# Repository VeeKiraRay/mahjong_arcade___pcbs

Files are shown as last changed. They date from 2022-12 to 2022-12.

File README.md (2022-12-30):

# Mahjong arcade DIY control panels
Kicad projects for a small mahjong control panel pcb that can be wired to be used with a real arcade game

Inspired by buffis JammaMahjongAdapter
https://github.com/buffis/JammaMahjongAdapter

Mahjong pinout that was followed when designing these
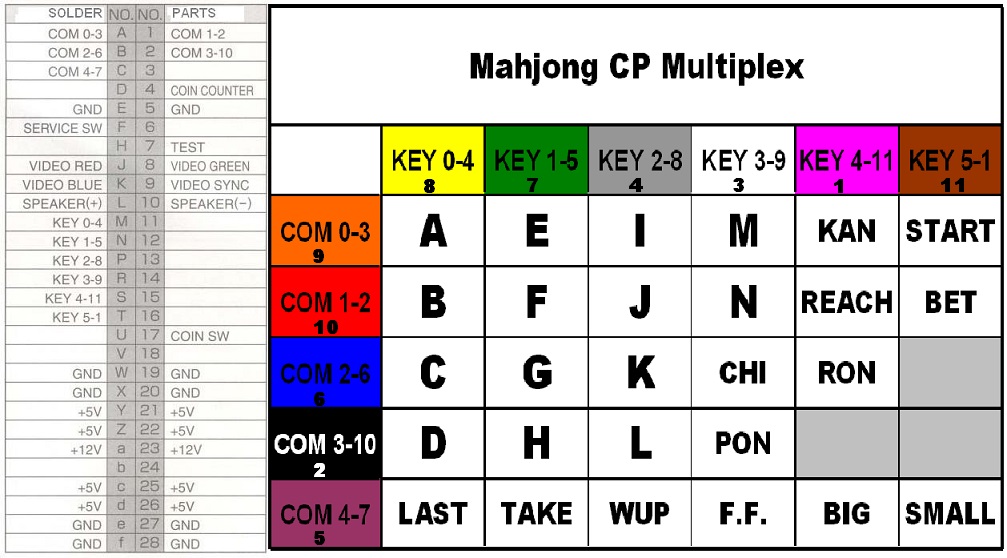
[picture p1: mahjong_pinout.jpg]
Mahjong pinout img


Comparison with different versions next to "Hot Gimmick 3" arcade pcb. Added a commercial version for Windows as a size comparison as well. 
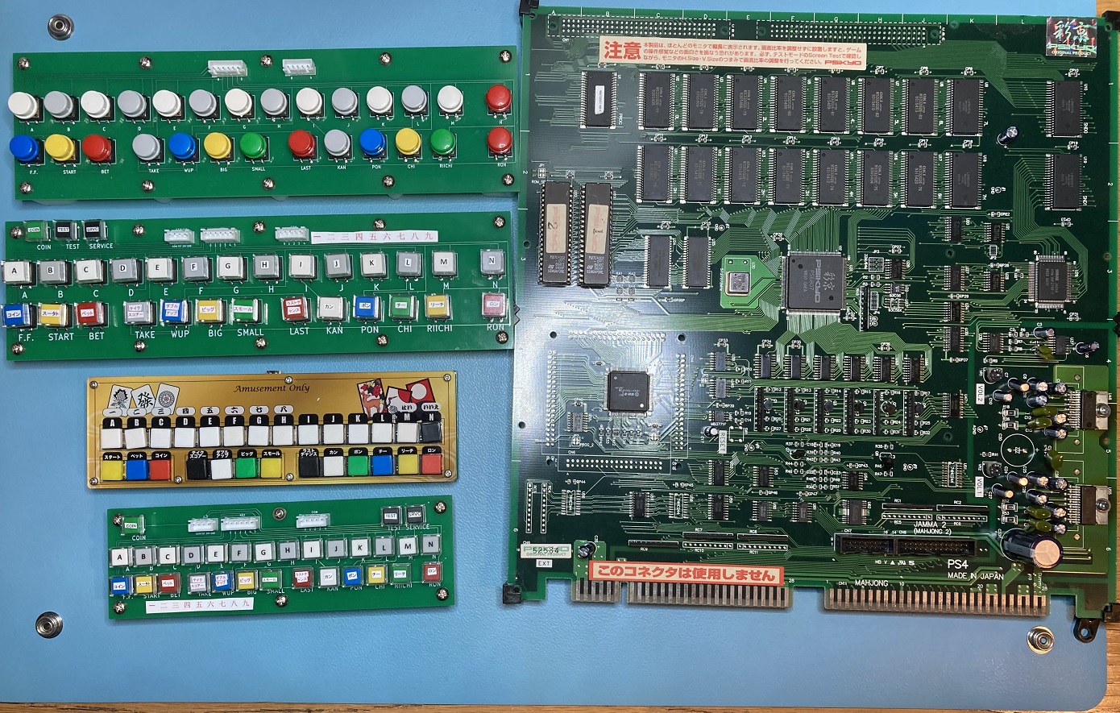
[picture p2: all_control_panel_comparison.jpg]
Comparison img


Ready to play with small control panel and mahjong to jamma adapter
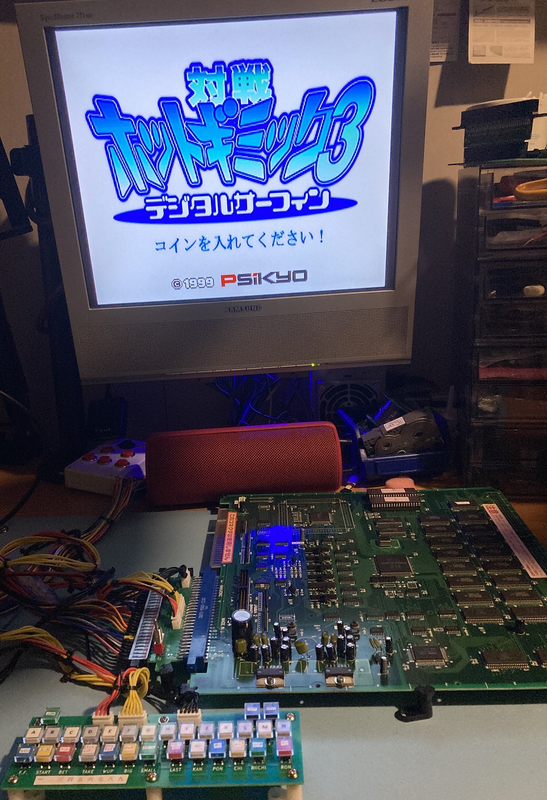
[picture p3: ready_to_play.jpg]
Ready_to_play img


## Mahjong control panel symbols
For printing stickers or otherwise marking control panels here are some of the common characters to use

Lower part of control panel
- coin (F.F.) / ko-i-n / コイン
- start / su-ta-a-to / スタート 
- bet / be-t-to / ベット
- take score / te-i-ku-su-ko / テイクスコアー
- double up (WUP) / da-bu-ru a-p-pu / ダブルアップ  
- big / bi-g-gu / ビッグ
- small / su-mo-ru / スモール
- last chance / ra-su-to ch-a-n-su / ラストチャンス
- kan / ka-n / カン
- pon / po-n / ポン
- chi / ch-i / チー
- riichi / ri-i-chi / リーチ
- ron / ro-n / ロン

Character suite to number conversion
- 1 / 一
- 2 / 二
- 3 / 三
- 4 / 四
- 5 / 五
- 6 / 六
- 7 / 七
- 8 / 八
- 9 / 九

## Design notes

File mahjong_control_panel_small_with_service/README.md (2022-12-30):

# Mahjong control panel small with service buttons

Smaller version of control panel with basic inputs and additional buttons for easy coin in, test for menus and service for alternative coin in and options.

- Connectors are with 2.5mm pitch, but 2.54mm should also work
- All buttons are 6mm. Any correct size button should work with or without the hats.
- Holes at the edge are M3 for attaching legs or to a case.

Bare pcb
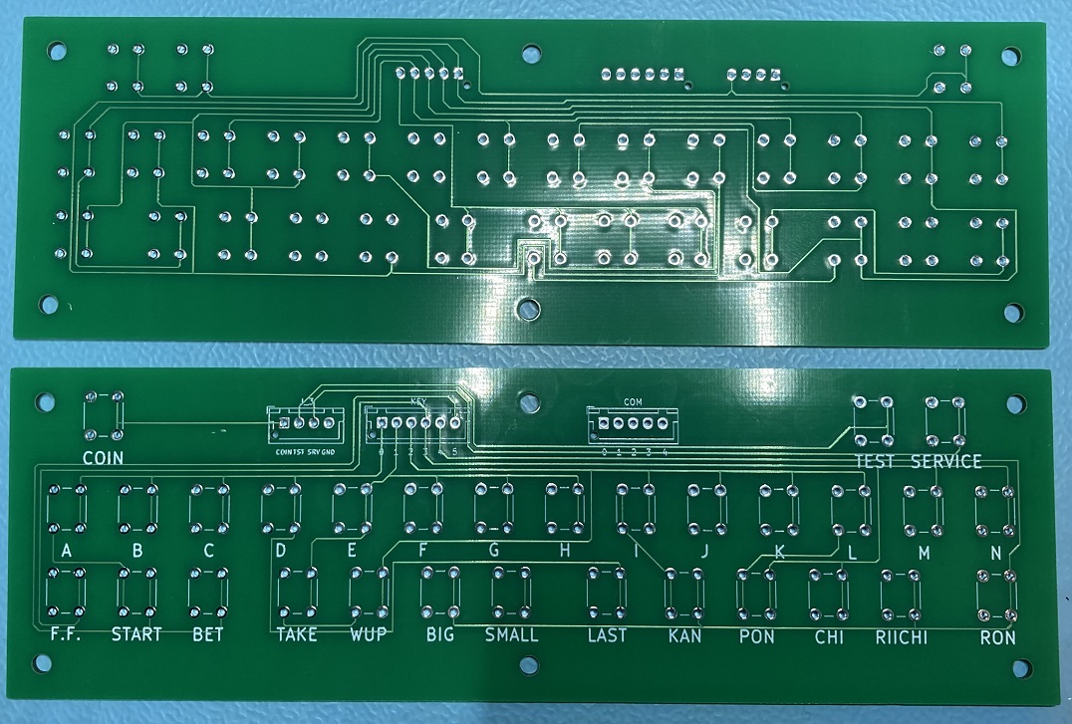
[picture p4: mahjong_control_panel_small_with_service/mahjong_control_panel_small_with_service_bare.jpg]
Bare pcb img


Control panel poulated
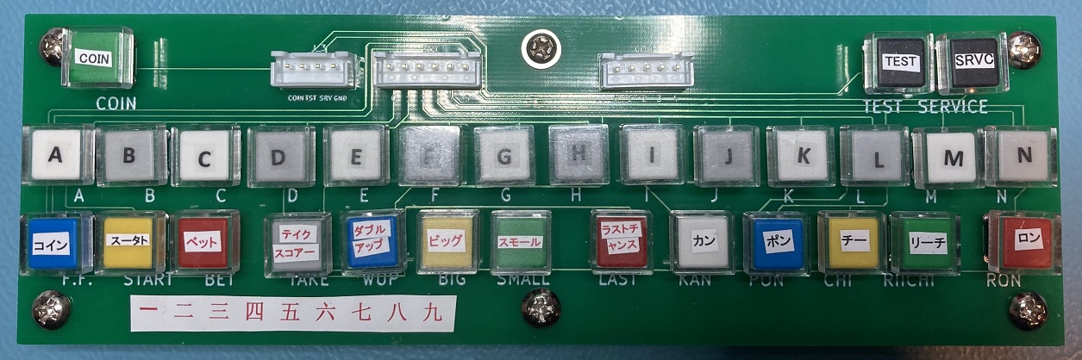
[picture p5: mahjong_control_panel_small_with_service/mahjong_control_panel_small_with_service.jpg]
Control panel populated img


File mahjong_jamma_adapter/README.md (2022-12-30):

# Mahjong to JAMMA adapter

Enables you to play Mahjong games in a JAMMA setup like arcade cabinet or supergun. 
This has 3.96mm pitch for the mahjong side pads which is same as with JAMMA. Note that some Mahjong games use 4mm pitch.
Be sure to check that the adapter lines with the game pcb pads correctly.

The main Mahjong controls can be extended with the 6- and 5-pin connectors. 
Additional 4-pin connector is also available for wiring coin, test and service buttons with GND.
Connector pins are with 2.5mm pitch, but 2.54mm should also work.

The -5V requirement and GND to "JAMMA Spk-" can be bridged if needed.

Audio section can be wired with a switch to change between connecting "JAMMA Spk-" to "Mahjong Spk-" or to GND.
Be sure what connections your game(s) require. For example Hot Gimmick needs the "JAMMA Spk-" to be connected to "Mahjong Spk-" or there won't be any sound.
Connecting this wrong can cause sound to be missing, distorted, low volume and possibly components overheating.

Mahjong pinout that was followed when designing this
Mahjong pinout img

Bare pcb
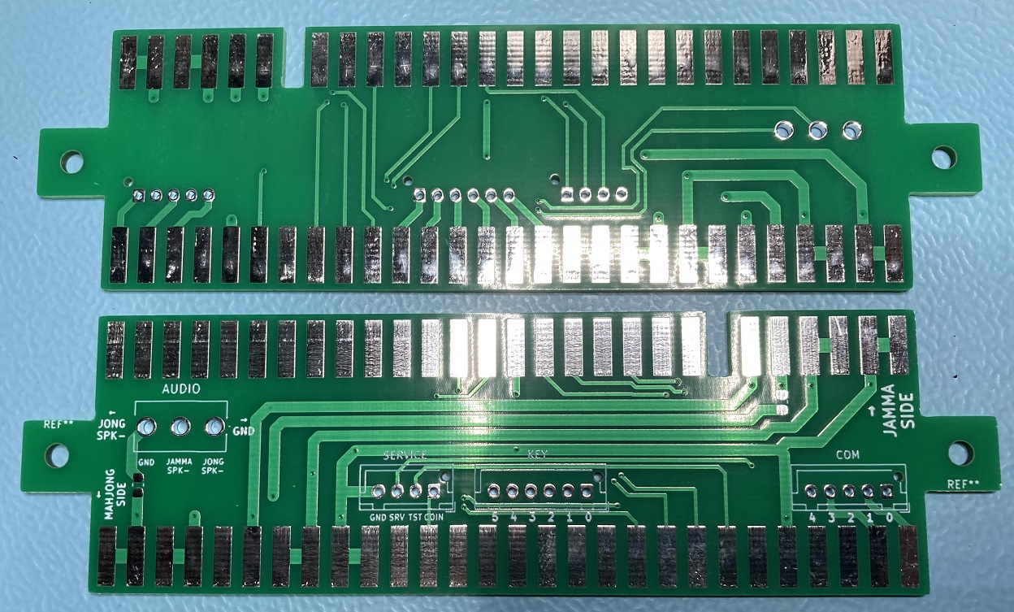
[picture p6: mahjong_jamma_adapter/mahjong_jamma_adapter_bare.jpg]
Bare pcb img


Control panel poulated
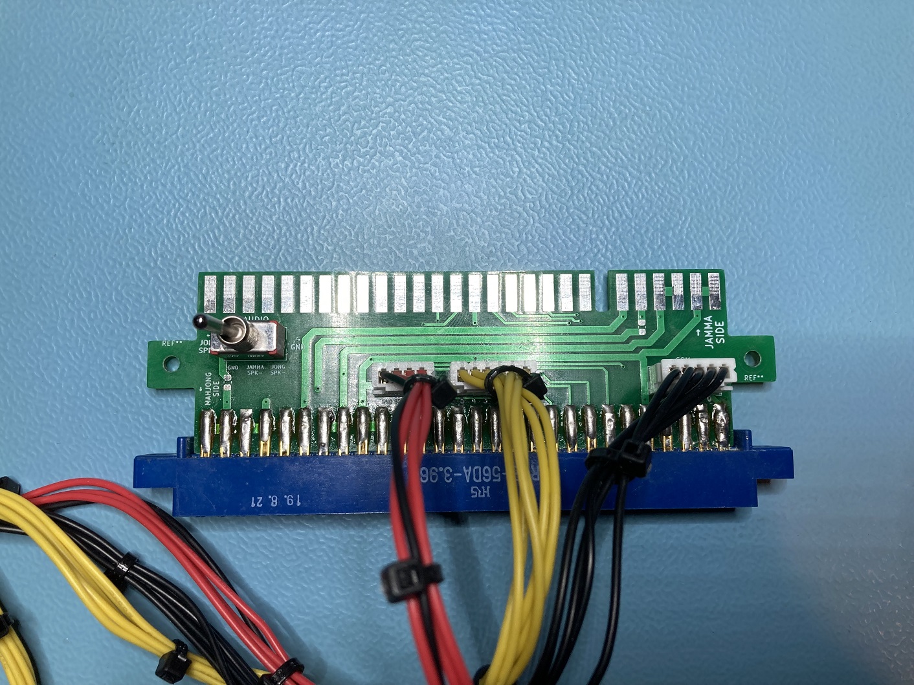
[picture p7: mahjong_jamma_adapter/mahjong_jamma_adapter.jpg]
Adapter populated img


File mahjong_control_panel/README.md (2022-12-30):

# Mahjong control panel

Control panel with just the basic inputs

- Connectors are with 2.5mm pitch, but 2.54mm should also work
- Main buttons are 12mm buttons. Any correct size button should work with or without the hats.
- Holes at the edge are M3 for attaching legs or to a case.

Bare pcb
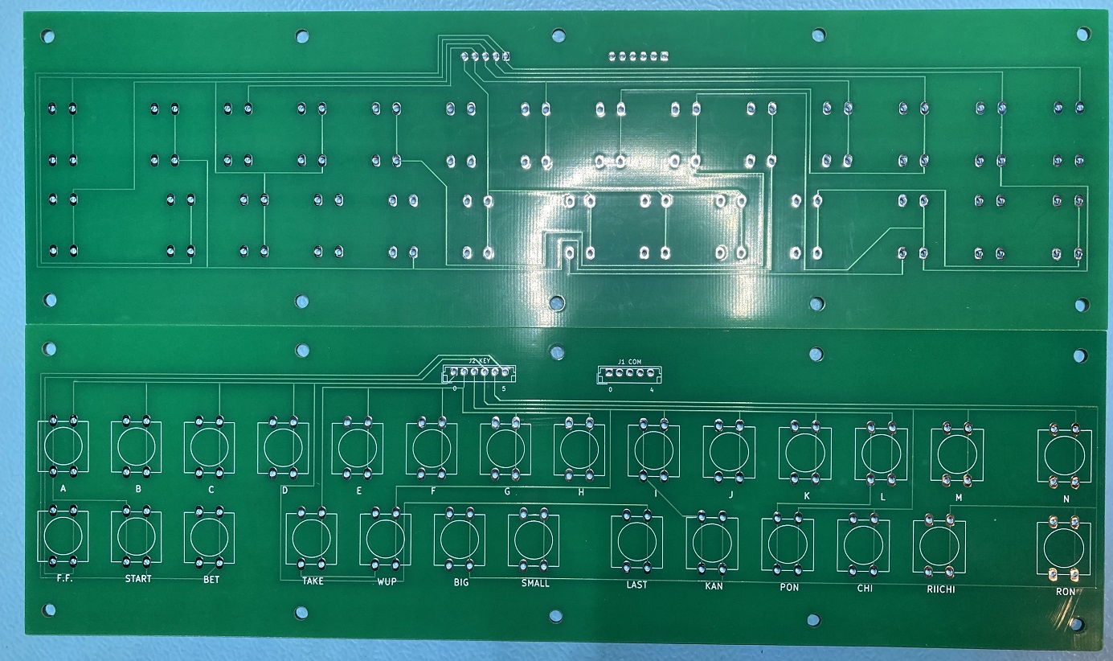
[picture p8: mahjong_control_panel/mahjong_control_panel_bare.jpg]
Bare pcb img


Control panel poulated
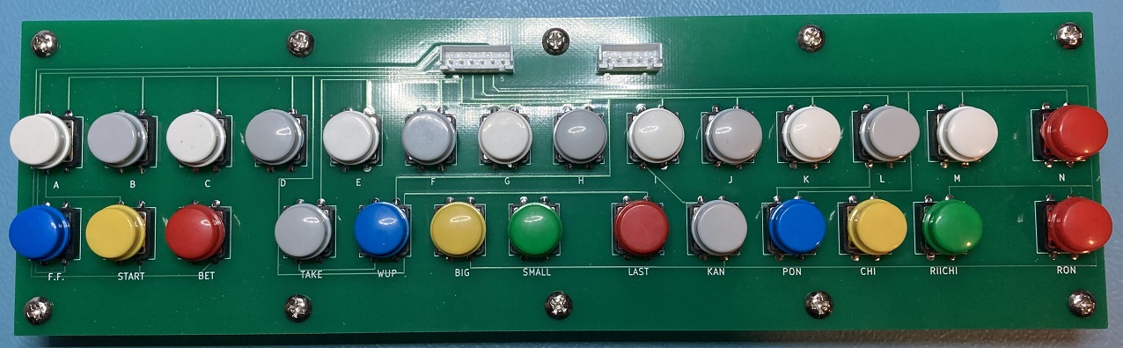
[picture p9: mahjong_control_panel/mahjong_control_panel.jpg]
Control panel populated img


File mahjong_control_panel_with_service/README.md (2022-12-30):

# Mahjong control panel with service buttons

Control panel with basic inputs and additional buttons for easy coin in, test for menus and service for alternative coin in and options.

- Connectors are with 2.5mm pitch, but 2.54mm should also work
- Main buttons are 12mm buttons and service buttons are 6mm. Any correct size button should work with or without the hats.
- Holes at the edge are M3 for attaching legs or to a case.

Bare pcb
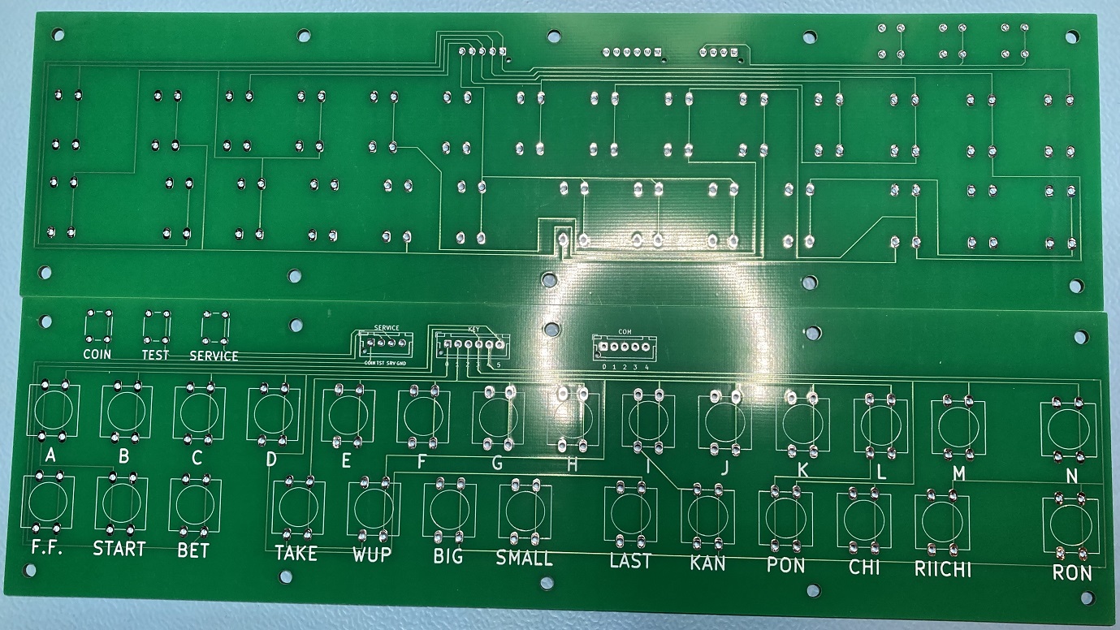
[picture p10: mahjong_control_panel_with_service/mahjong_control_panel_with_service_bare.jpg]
Bare pcb img


Control panel poulated
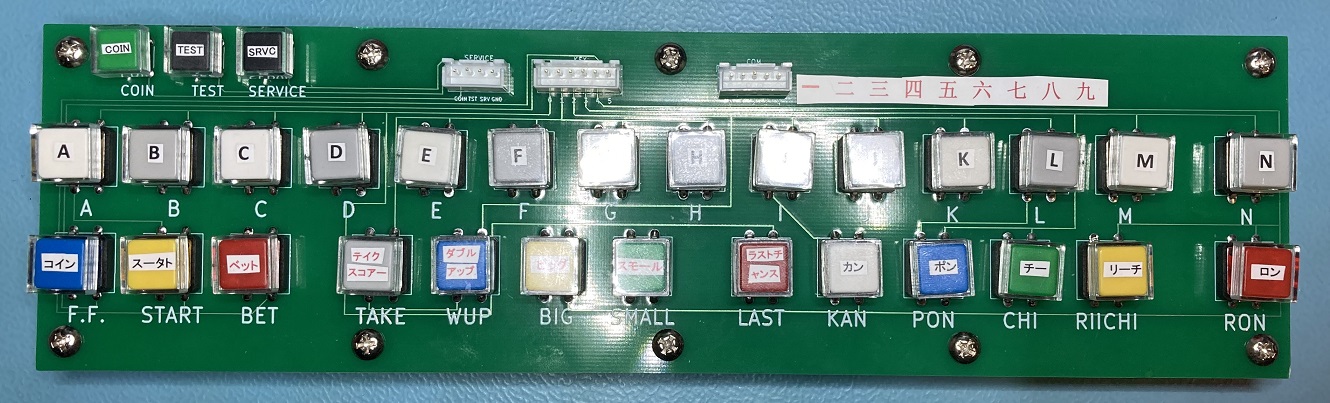
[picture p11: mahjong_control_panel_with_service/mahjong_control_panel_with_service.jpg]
Control panel populated img


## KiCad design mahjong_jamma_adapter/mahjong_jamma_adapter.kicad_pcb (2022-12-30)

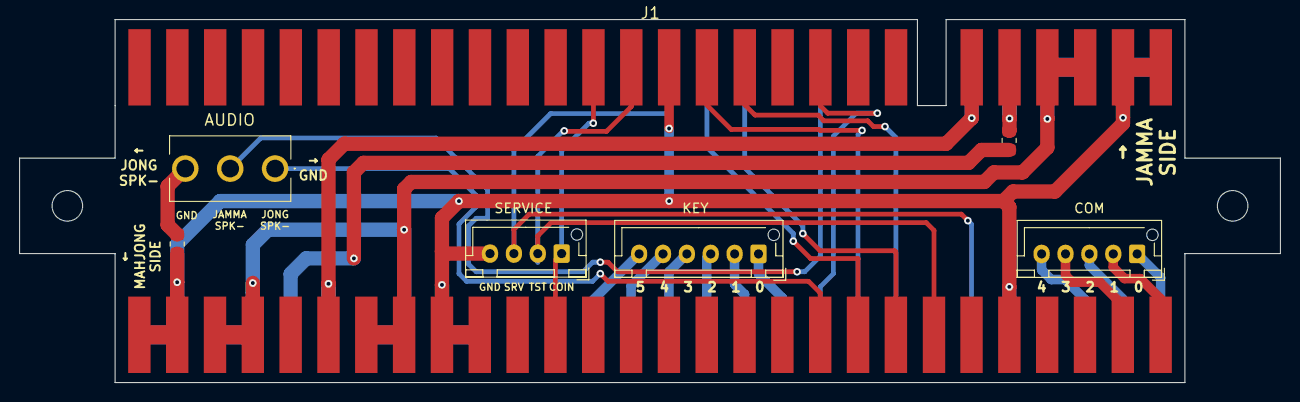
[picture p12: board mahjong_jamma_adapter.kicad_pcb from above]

Board: 2 copper layers, 132.0 x 38.0 mm, 8 parts (0 on the bottom side), 27 nets.

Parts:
AUDIO: Mahjong_Connector; MAHJONG-56
COM: Conn_01x05; JST_XH_B5B-XH-AM_1x05_P2.50mm_Vertical
J1: Jamma_Connector; JAMMA-56
JMP1, JMP2: SolderJumper_2_Open; R_0805_2012Metric_Pad1.20x1.40mm_HandSolder
KEY: Conn_01x06; JST_XH_B6B-XH-AM_1x06_P2.50mm_Vertical
SERVICE: Conn_01x04; JST_XH_B4B-XH-AM_1x04_P2.50mm_Vertical
SW1: SW_SPDT; A101SYCQ04

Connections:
5V: AUDIO.21, AUDIO.22, AUDIO.25, AUDIO.26, AUDIO.Y, AUDIO.Z, AUDIO.c, AUDIO.d, J1.3, J1.4, J1.C, J1.D
12V: AUDIO.23, AUDIO.a, J1.6, J1.F
-5V: J1.5, J1.E, JMP1.2 (B)
-5V_M: AUDIO.b, JMP1.1 (A)
BLUE: AUDIO.K, J1.13
COIN: AUDIO.17, J1.16, SERVICE.1
COM0-3: AUDIO.A, COM.1
COM1-2: AUDIO.1, COM.2
COM2-6: AUDIO.B, COM.3
COM3-10: AUDIO.2, COM.4
COM4-7: AUDIO.C, COM.5
GND: AUDIO.5, AUDIO.19, AUDIO.20, AUDIO.27, AUDIO.28, AUDIO.E, AUDIO.W, AUDIO.X, AUDIO.e, AUDIO.f, J1.1, J1.2, J1.14, J1.A, J1.B, JMP2.2 (B), SERVICE.4
GREEN: AUDIO.8, J1.N
JAMMA_SPK-: J1.L, SW1.2 (B)
JONG_SPK-: AUDIO.10, SW1.1 (A)
KEY0-4: AUDIO.M, KEY.1
KEY1-5: AUDIO.N, KEY.2
KEY2-8: AUDIO.P, KEY.3
KEY3-9: AUDIO.R, KEY.4
KEY4-11: AUDIO.S, KEY.5
KEY5-1: AUDIO.T, KEY.6
unnamed: JMP2.1 (A), SW1.3 (C)
RED: AUDIO.J, J1.12
SERVICE: AUDIO.F, J1.R, SERVICE.3
SPK+: AUDIO.L, J1.10
SYNC: AUDIO.9, J1.P
TEST: AUDIO.7, J1.15, SERVICE.2

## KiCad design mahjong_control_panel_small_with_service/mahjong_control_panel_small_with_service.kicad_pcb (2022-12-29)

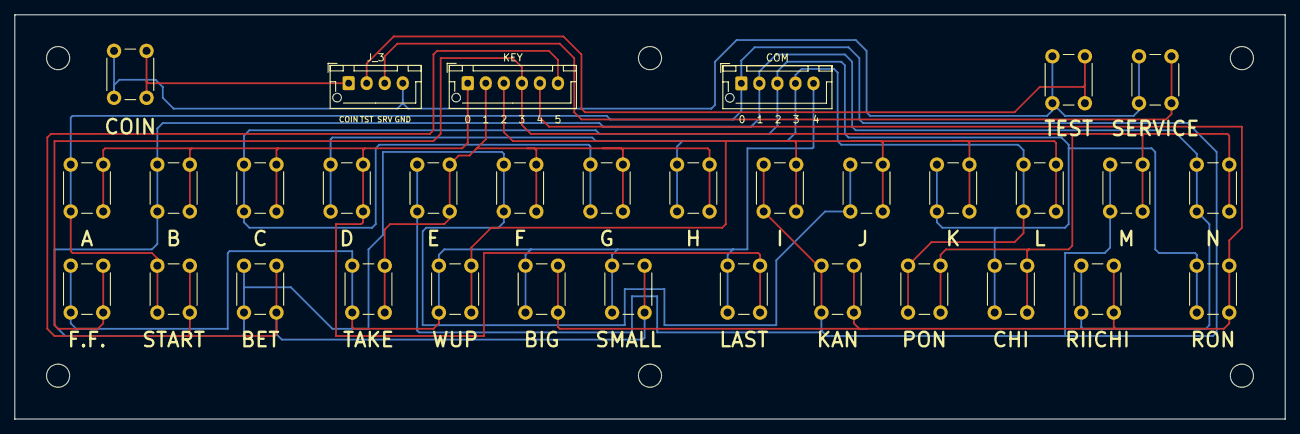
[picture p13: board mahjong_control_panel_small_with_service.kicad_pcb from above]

Board: 2 copper layers, 176.0 x 56.0 mm, 33 parts (0 on the bottom side), 15 nets.

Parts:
A: SW_A; SW_PUSH_6mm_H7.3mm
B: SW_B; SW_PUSH_6mm_H7.3mm
BET: SW_BET; SW_PUSH_6mm_H7.3mm
BIG: SW_BIG; SW_PUSH_6mm_H7.3mm
C: SW_C; SW_PUSH_6mm_H7.3mm
CHI: SW_CHI; SW_PUSH_6mm_H7.3mm
COIN: SW_COIN; SW_PUSH_6mm_H7.3mm
COM: Conn_01x05; JST_XH_B5B-XH-AM_1x05_P2.50mm_Vertical
D: SW_D; SW_PUSH_6mm_H7.3mm
E: SW_E; SW_PUSH_6mm_H7.3mm
F: SW_F; SW_PUSH_6mm_H7.3mm
F.F.: SW_F.F.; SW_PUSH_6mm_H7.3mm
G: SW_G; SW_PUSH_6mm_H7.3mm
H: SW_H; SW_PUSH_6mm_H7.3mm
I: SW_I; SW_PUSH_6mm_H7.3mm
J: SW_J; SW_PUSH_6mm_H7.3mm
J_3: Conn_01x04; JST_XH_B4B-XH-AM_1x04_P2.50mm_Vertical
K: SW_K; SW_PUSH_6mm_H7.3mm
KAN: SW_KAN; SW_PUSH_6mm_H7.3mm
KEY: Conn_01x06; JST_XH_B6B-XH-AM_1x06_P2.50mm_Vertical
L: SW_L; SW_PUSH_6mm_H7.3mm
LAST: SW_LAST; SW_PUSH_6mm_H7.3mm
M: SW_M; SW_PUSH_6mm_H7.3mm
N: SW_N; SW_PUSH_6mm_H7.3mm
PON: SW_PON; SW_PUSH_6mm_H7.3mm
RIICHI: SW_REACH; SW_PUSH_6mm_H7.3mm
RON: SW_RON; SW_PUSH_6mm_H7.3mm
SERVICE: SW_SERVICE; SW_PUSH_6mm_H7.3mm
SMALL: SW_SMALL; SW_PUSH_6mm_H7.3mm
START: SW_START; SW_PUSH_6mm_H7.3mm
TAKE: SW_TAKE; SW_PUSH_6mm_H7.3mm
TEST: SW_TEST; SW_PUSH_6mm_H7.3mm
WUP: SW_WUP; SW_PUSH_6mm_H7.3mm

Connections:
COM0-3: A.1 (C), COM.1, E.1 (C), I.1 (C), KAN.1 (C), M.1 (C), START.1 (C)
COM1-2: B.1 (C), BET.1 (C), COM.2, F.1 (C), J.1 (C), N.1 (C), RIICHI.1 (C)
COM2-6: C.1 (C), CHI.1 (C), COM.3, G.1 (C), K.1 (C), RON.1 (C)
COM3-10: COM.4, D.1 (C), H.1 (C), L.1 (C), PON.1 (C)
COM4-7: BIG.1 (C), COM.5, F.F..1 (C), LAST.1 (C), SMALL.1 (C), TAKE.1 (C), WUP.1 (C)
Coin: COIN.2 (D), J_3.1
GND: COIN.1 (C), J_3.4, SERVICE.1 (C), TEST.1 (C)
KEY0-4: A.2 (D), B.2 (D), C.2 (D), D.2 (D), KEY.1, LAST.2 (D)
KEY1-5: E.2 (D), F.2 (D), G.2 (D), H.2 (D), KEY.2, TAKE.2 (D)
KEY2-8: I.2 (D), J.2 (D), K.2 (D), KEY.3, L.2 (D), WUP.2 (D)
KEY3-9: CHI.2 (D), F.F..2 (D), KEY.4, M.2 (D), N.2 (D), PON.2 (D)
KEY4-11: BIG.2 (D), KAN.2 (D), KEY.5, RIICHI.2 (D), RON.2 (D)
KEY5-1: BET.2 (D), KEY.6, SMALL.2 (D), START.2 (D)
Service: J_3.3, SERVICE.2 (D)
Test: J_3.2, TEST.2 (D)

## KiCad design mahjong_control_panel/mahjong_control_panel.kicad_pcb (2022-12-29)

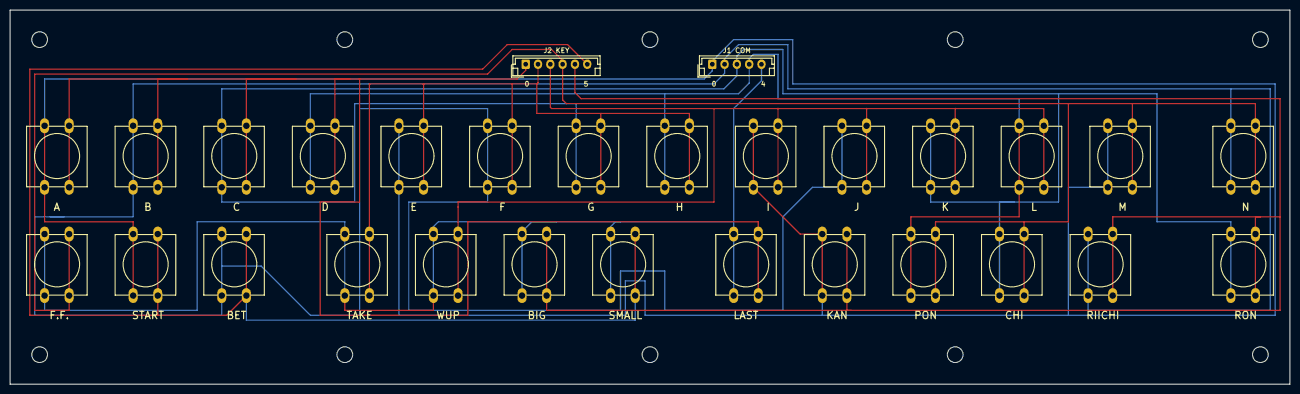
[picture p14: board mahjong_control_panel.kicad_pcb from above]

Board: 2 copper layers, 260.0 x 76.0 mm, 29 parts (0 on the bottom side), 11 nets.

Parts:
A: SW_A; SW_PUSH-12mm
B: SW_B; SW_PUSH-12mm
BET: SW_BET; SW_PUSH-12mm
BIG: SW_BIG; SW_PUSH-12mm
C: SW_C; SW_PUSH-12mm
CHI: SW_CHI; SW_PUSH-12mm
D: SW_D; SW_PUSH-12mm
E: SW_E; SW_PUSH-12mm
F: SW_F; SW_PUSH-12mm
F.F.: SW_F.F.; SW_PUSH-12mm
G: SW_G; SW_PUSH-12mm
H: SW_H; SW_PUSH-12mm
I: SW_I; SW_PUSH-12mm
J: SW_J; SW_PUSH-12mm
J1 COM: Conn_01x05; JST_EH_B5B-EH-A_1x05_P2.50mm_Vertical
J2 KEY: Conn_01x06; JST_EH_B6B-EH-A_1x06_P2.50mm_Vertical
K: SW_K; SW_PUSH-12mm
KAN: SW_KAN; SW_PUSH-12mm
L: SW_L; SW_PUSH-12mm
LAST: SW_LAST; SW_PUSH-12mm
M: SW_M; SW_PUSH-12mm
N: SW_N; SW_PUSH-12mm
PON: SW_PON; SW_PUSH-12mm
RIICHI: SW_REACH; SW_PUSH-12mm
RON: SW_RON; SW_PUSH-12mm
SMALL: SW_SMALL; SW_PUSH-12mm
START: SW_START; SW_PUSH-12mm
TAKE: SW_TAKE; SW_PUSH-12mm
WUP: SW_WUP; SW_PUSH-12mm

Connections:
COM0-3: A.1 (C), E.1 (C), I.1 (C), J1 COM.1, KAN.1 (C), M.1 (C), START.1 (C)
COM1-2: B.1 (C), BET.1 (C), F.1 (C), J.1 (C), J1 COM.2, N.1 (C), RIICHI.1 (C)
COM2-6: C.1 (C), CHI.1 (C), G.1 (C), J1 COM.3, K.1 (C), RON.1 (C)
COM3-10: D.1 (C), H.1 (C), J1 COM.4, L.1 (C), PON.1 (C)
COM4-7: BIG.1 (C), F.F..1 (C), J1 COM.5, LAST.1 (C), SMALL.1 (C), TAKE.1 (C), WUP.1 (C)
KEY0-4: A.2 (D), B.2 (D), C.2 (D), D.2 (D), J2 KEY.1, LAST.2 (D)
KEY1-5: E.2 (D), F.2 (D), G.2 (D), H.2 (D), J2 KEY.2, TAKE.2 (D)
KEY2-8: I.2 (D), J.2 (D), J2 KEY.3, K.2 (D), L.2 (D), WUP.2 (D)
KEY3-9: CHI.2 (D), F.F..2 (D), J2 KEY.4, M.2 (D), N.2 (D), PON.2 (D)
KEY4-11: BIG.2 (D), J2 KEY.5, KAN.2 (D), RIICHI.2 (D), RON.2 (D)
KEY5-1: BET.2 (D), J2 KEY.6, SMALL.2 (D), START.2 (D)

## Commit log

2022-12-29 Initial commit for projects
    [mahjong_control_panel-B_Cu.gbr, mahjong_control_panel-B_Mask.gbr, mahjong_control_panel-B_Paste.gbr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]
2022-12-29 Refactor folder names and improve README
    [mahjong_control_panel_small_with_service-B_Cu.gbr, mahjong_control_panel_small_with_service-B_Mask.gbr, mahjong_control_panel_small_with_service-B_Paste.gbr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]
2022-12-30 Add mahjong to jamma adapter
    [mahjong_jamma_adapter-B_Cu.gbr, mahjong_jamma_adapter-B_Mask.gbr, mahjong_jamma_adapter-B_Paste.gbr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]
